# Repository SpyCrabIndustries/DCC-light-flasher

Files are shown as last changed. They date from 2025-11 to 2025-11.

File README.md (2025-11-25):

# DCC-light-flasher
DCC light flasher PCB

this is a quick and dirty PCB for at attiny85 based DCC decoder for turning lights on on rolling stock ect. right now all the markdown and files are kinda a mess.
if aanyone wants to sort it and make a PR be my guest ;3 

currently the only thing up here was made to do this: https://www.youtube.com/watch?v=XgUUQQwzfhY 
gerber files are in the folder labeled gerber.
the schematic & BOM is in the folder labeled schematic !!!check the schematic befor fabbing this i have not tested it!!! 
the whole kicad folde is also up here so yall can mess with it if you'd like.

have fun! ill clean this up at some point (lol, famous last words)

oh, and if something needs to be changed let me know

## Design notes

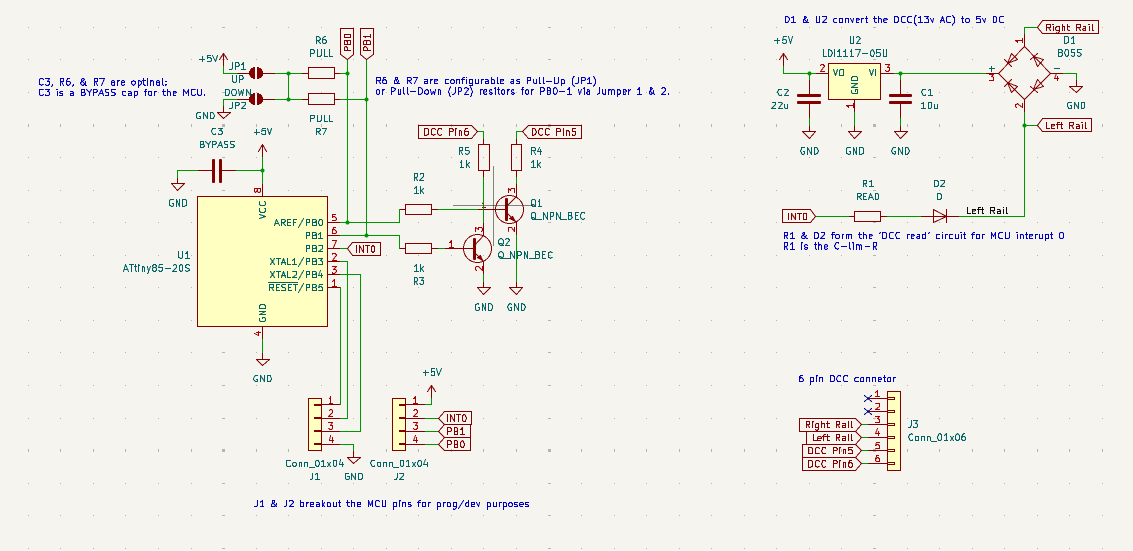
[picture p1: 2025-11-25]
schematic/schmatic.png

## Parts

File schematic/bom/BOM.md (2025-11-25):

all resistors and cap should be 0805 size SMD

C1 10uF 0805 (smoothing for LDO)
C2 22uf 0805 (smoothing for LDO)
C3 10nf 0805 *optional* (bypass cap for MCU)

R1 ???? 0805 (this is the resistor that gose to the DCC rail IDK what its value is)
R2, R3 1k 0805 (these are the base resistors for Q1 & Q2, there was a big deal made finding the value of these, truth be told its not that important here [i think])
R4, R5 1k 0805 (these are the current limiting resistors for the LEDs in the train car)
R6, R7 10k 0805 *optional* (these are the optional pull up or pull down resistors for the GPIO lines going to Q1 & Q2. if you have problems with both outputs turning on when they shouldnt these may help: BUT YOU MUST ALSO SOLDER EITHER THE UP OR DOWN JUMPER [probably the DOWN jumper, that makes them off by defualt] just to be clear you dont need to install these unless you have an issue)

D1 B05S (this is the rectifer, i think you where using a B05S this should be the right size for that if you want to be sure you can look at the datasheet for your part and see if it says pakage:To-269AA)
D2 ???? SOD-123 (this is the reverse current protection diode it is a SOD-123 pakage which is a very common SMD diode. i think it is what you where using.)

U1 AtTiny85 (this is the MCU)
U2 LDI11117-05U (this is the LDO, the voltage regulator. this is the only part i wasnt sure about: idk if this is what you where using. if you go looking for this part make sure its says 05 [thats the voltage] after the '-' [the letter after the 5 dose not matter for this] )

Q1 & Q2 (standard NPN transitors set up as BEC meaning pin 1 is the base, pin 2 is the collector, and pin 3 is the emitter: like the ones you have in the video )

J1 & J2 (these are standared pin headers, they will allow you to proggram the MCU just like the breakout board you had. might not fit on a breadboard tho)
J3 (this is the DCC 6 pin connector with pin one shown by the triangle)

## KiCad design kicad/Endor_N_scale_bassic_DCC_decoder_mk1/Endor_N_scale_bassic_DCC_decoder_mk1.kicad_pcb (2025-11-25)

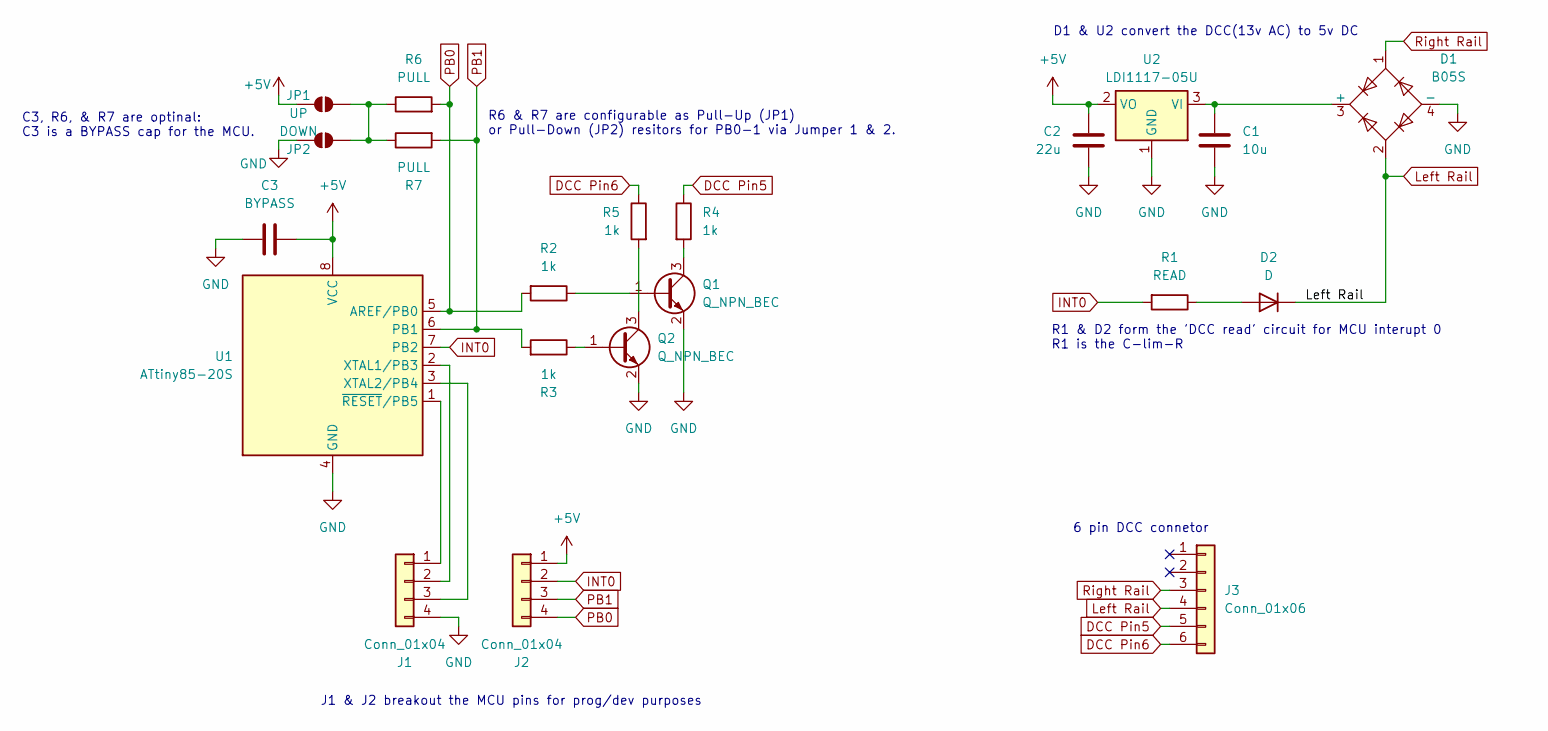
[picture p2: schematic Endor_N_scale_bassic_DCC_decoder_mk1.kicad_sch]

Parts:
C1: 10u; C_0805_2012Metric_Pad1.18x1.45mm_HandSolder
C2: 22u; C_0805_2012Metric_Pad1.18x1.45mm_HandSolder
C3: BYPASS; C_0805_2012Metric_Pad1.18x1.45mm_HandSolder
D1: B05S; TO-269AA
D2: D; D_SOD-123
J1, J2: Conn_01x04; PinHeader_1x04_P1.27mm_Vertical
J3: Conn_01x06; PinHeader_1x06_P1.27mm_Vertical
JP1: UP; SolderJumper-2_P1.3mm_Open_TrianglePad1.0x1.5mm
JP2: DOWN; SolderJumper-2_P1.3mm_Open_TrianglePad1.0x1.5mm
Q1, Q2: Q_NPN_BEC; SOT-23_Handsoldering
R1: READ; R_0805_2012Metric_Pad1.20x1.40mm_HandSolder
R2, R3, R4, R5: 1k; R_0805_2012Metric_Pad1.20x1.40mm_HandSolder
R6, R7: PULL; R_0805_2012Metric_Pad1.20x1.40mm_HandSolder
U1: ATtiny85-20S; SOIC-8_5.3x5.3mm_P1.27mm
U2: LDI1117-05U; SOT-89-3_Handsoldering

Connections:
+5V: C2.1, C3.2, J2.1, JP1.1 (A), U1.8 (VCC), U2.2 (VO); also elsewhere on the board
DCC Pin5: J3.5, R4.1
DCC Pin6: J3.6, R5.1
GND: C1.2, C2.2, C3.1, D1.4 (-), J1.4, JP2.1 (A), Q1.2 (E), Q2.2 (E), U1.4 (GND), U2.1 (GND); also elsewhere on the board
INT0: J2.2, R1.2, U1.7 (PB2)
Left Rail: D1.2, D2.1 (K), J3.4
unnamed: C1.1, D1.3 (+), U2.3 (VI)
unnamed: D2.2 (A), R1.1
unnamed: J1.1, U1.1 (~RESET/PB5)
unnamed: J1.2, U1.2 (XTAL1/PB3)
unnamed: J1.3, U1.3 (XTAL2/PB4)
unnamed 11: JP1.2 (B), JP2.2 (B), R6.1, R7.1; also elsewhere on the board
unnamed: Q1.1 (B), R2.1
unnamed: Q1.3 (C), R4.2
unnamed: Q2.1 (B), R3.1
unnamed: Q2.3 (C), R5.2
PB0: J2.4, R2.2, R6.2, U1.5 (AREF/PB0)
PB1: J2.3, R3.2, R7.2, U1.6 (PB1)
Right Rail: D1.1, J3.3

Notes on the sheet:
R6 & R7 are configurable as Pull-Up (JP1) or Pull-Down (JP2) resitors for PB0-1 via Jumper 1 & 2.
D1 & U2 convert the DCC(13v AC) to 5v DC
6 pin DCC connetor
R1 & D2 form the 'DCC read' circuit for MCU interupt 0 R1 is the C-lim-R
J1 & J2 breakout the MCU pins for prog/dev purposes
C3, R6, & R7 are optinal: C3 is a BYPASS cap for the MCU.

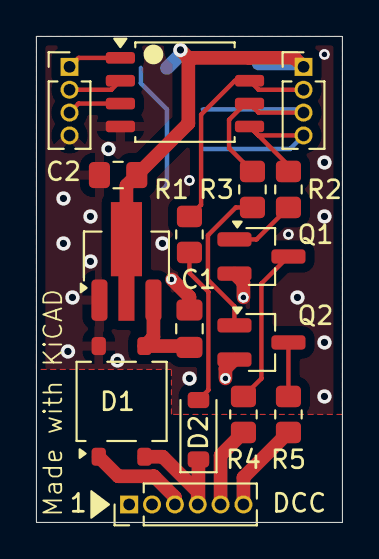
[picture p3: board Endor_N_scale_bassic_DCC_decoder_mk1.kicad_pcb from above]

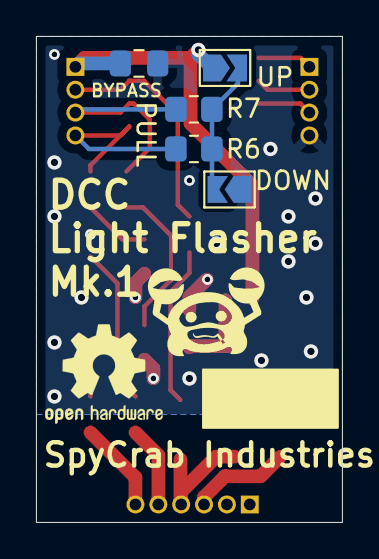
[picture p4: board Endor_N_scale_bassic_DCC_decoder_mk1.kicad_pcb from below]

Board: 2 copper layers, 17.0 x 27.0 mm, 21 parts (5 on the bottom side), 19 nets.

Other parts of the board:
DOWN: DOWN; SolderJumper-2_P1.3mm_Open_TrianglePad1.0x1.5mm
UP: UP; SolderJumper-2_P1.3mm_Open_TrianglePad1.0x1.5mm

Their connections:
+5V: UP.1 (A); also elsewhere on the board
GND: DOWN.1 (A); also elsewhere on the board
unnamed 11: DOWN.2 (B), UP.2 (B); also elsewhere on the board

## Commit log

2025-11-25 added everthing
    [Endor_N_scale_bassic_DCC_decoder_mk1-B_Cu.gbr, Endor_N_scale_bassic_DCC_decoder_mk1-B_Mask.gbr, Endor_N_scale_bassic_DCC_decoder_mk1-B_Paste.gbr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]
2025-11-25 added kicad file, fixed image?
    [Endor_N_scale_bassic_DCC_decoder_mk1-B_Cu.gbr, Endor_N_scale_bassic_DCC_decoder_mk1-B_Mask.gbr, Endor_N_scale_bassic_DCC_decoder_mk1-B_Paste.gbr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]
